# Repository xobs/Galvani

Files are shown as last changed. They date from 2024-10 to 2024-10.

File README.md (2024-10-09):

# Galvani AC LED Controller

A controller for driving pretty lights from AC-driven trains by connecting roller pickups.

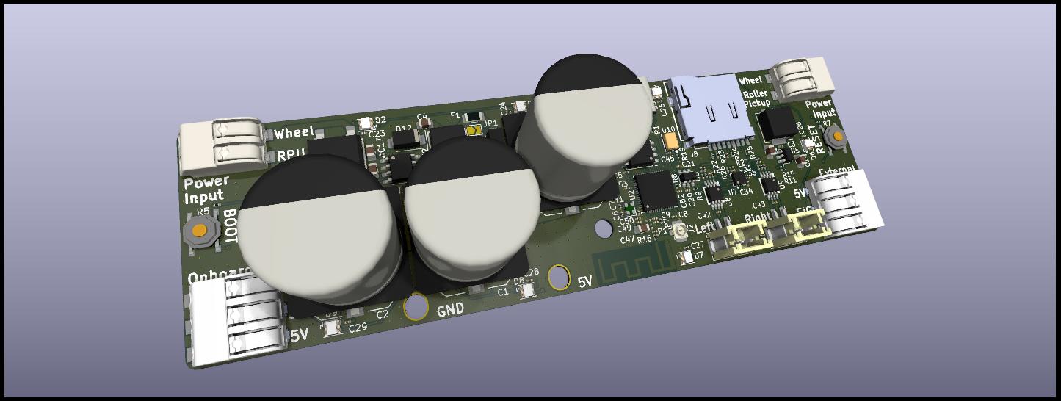
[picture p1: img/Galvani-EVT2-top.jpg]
EVT2 PCB render


Galvani is rated to drive 3 Amps. This is around 40 lights at full bright white, plus the wifi access point. Exceeding this value trips a resettable fuse.

Only run full LEDs when driving from a power supply. When running from USB, only use the onboard LEDs.

## Installation

Install WLED for the ESP32S3. Hold down the "PROG" button as plug in the USB cable. Alternately, hold down "PROG" and press "RESET".

Then, load the firmware using `esptool` or `probe-rs`.

## Testing the LEDs

You should be able to power a short string of LEDs from USB, depending on how much power your USB port can supply.

Use the built-in web interface on WLED. Connect to the access point labelled `WLED-AP`. The password is `wled1234`. Then go to the address `4.3.2.1` in your browser.

You can download an [iOS App](https://apps.apple.com/us/app/wled-native/id6446207239) or [Android App](https://play.google.com/store/apps/details?id=com.pixelheart.wledplus) to control the lights from your phone or tablet.

## Connecting LED Strips

The onboard LEDs are connected to GPIO2. There are 8 onboard LEDs. The end of these LEDs go to the "Onboard" connector, allowing you to add more lights to this string.

There is also an "External" connector. This is connected to GPIO6 and has no onboard LEDs. You can use this connector to avoid having to skip the 8 onboard LEDs when driving a string.

## Connecting to the Roller Pickups

There are two roller pickup connectors. This is designed for setups where there are two pickups to ensure continuity when crossing track connections. You can operate with just one roller pickup, but that may affect the number of lights you can power, and there may be brownouts when crossing segments.

Connect the roller pickup to the connector marked "RPU". If you have two roller pickups, connect each of them to the two connectors.

Next, run a wire from the "EARTH" pin to the wheels. This will provide a return path.

There is no problem connecting both the roller pickups and USB at the same time -- there are a pair of diodes protecting each of the power sources.

**IMPORTANT**: Do not cross-connect RPU and EARTH! That is, do not connect RPU to the roller pickup on one side and RPU to the wheels on the other side! This will create a dead-short.

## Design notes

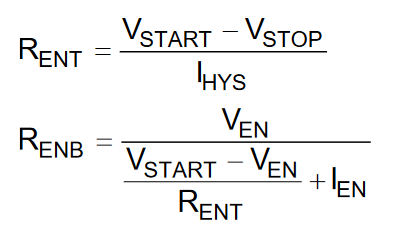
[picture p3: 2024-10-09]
img/12v-uvlo-equation.png

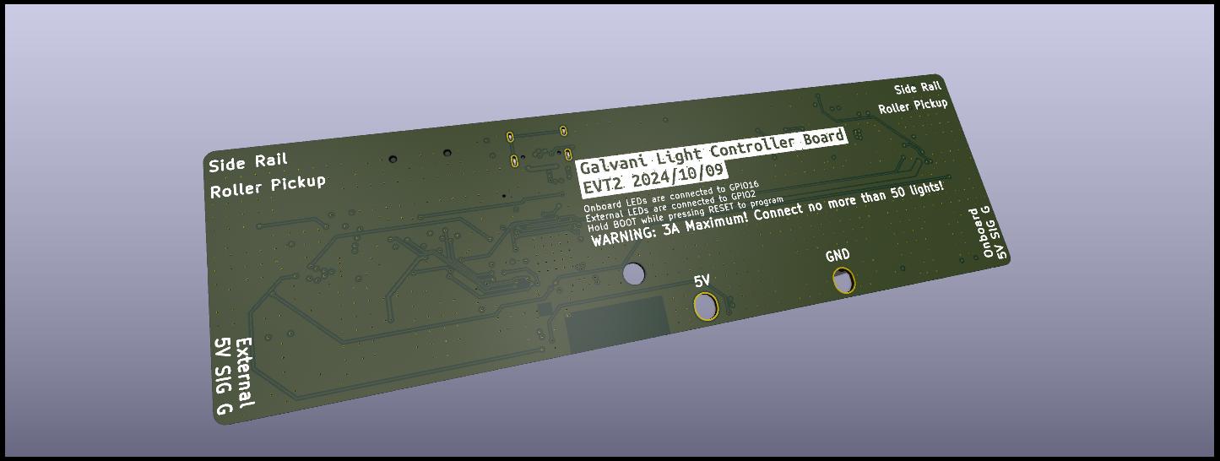
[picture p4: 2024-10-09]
img/Galvani-EVT2-bottom.jpg

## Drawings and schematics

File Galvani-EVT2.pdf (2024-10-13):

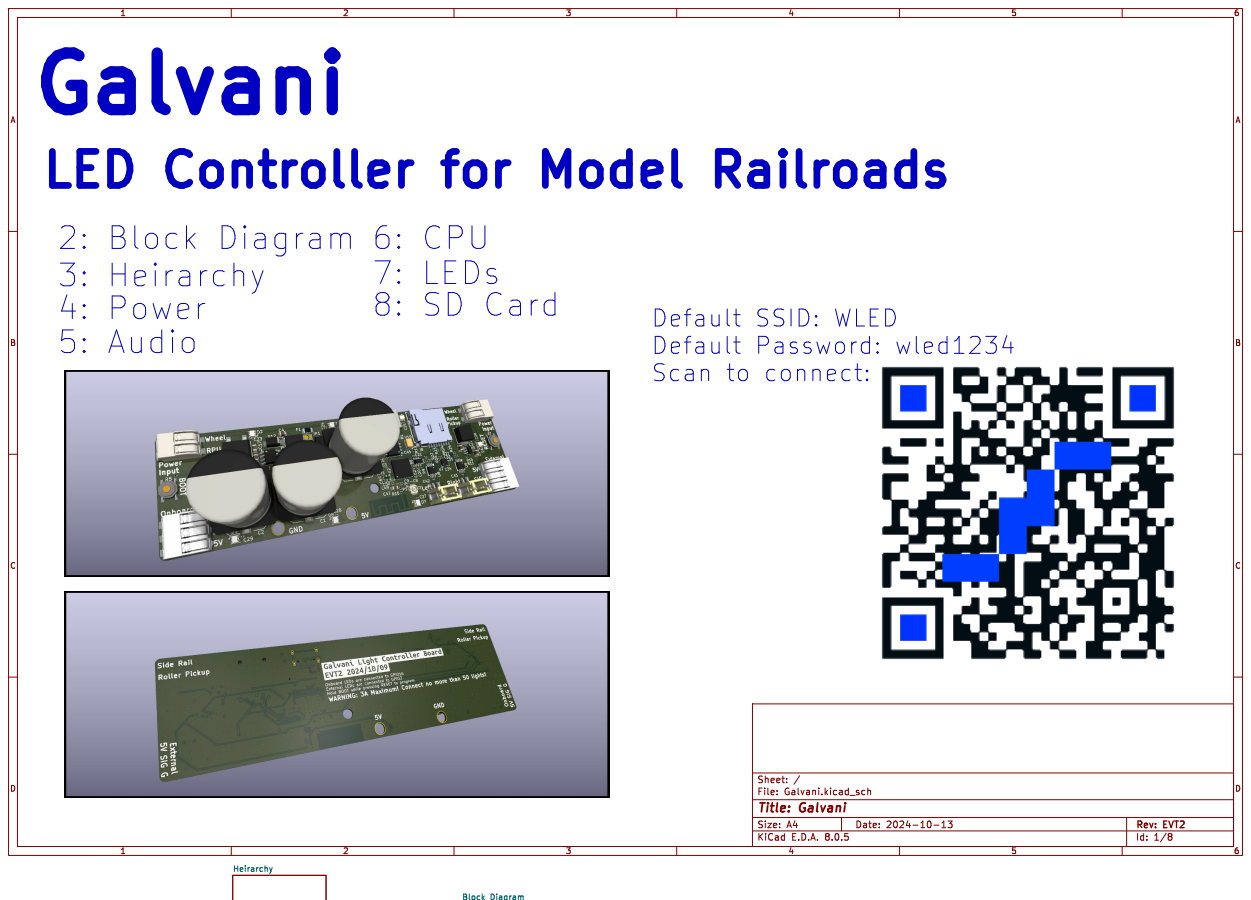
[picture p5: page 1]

Id: 1/8 Title: Galvani File: Galvani.kicad_sch Sheet: / Block Diagram

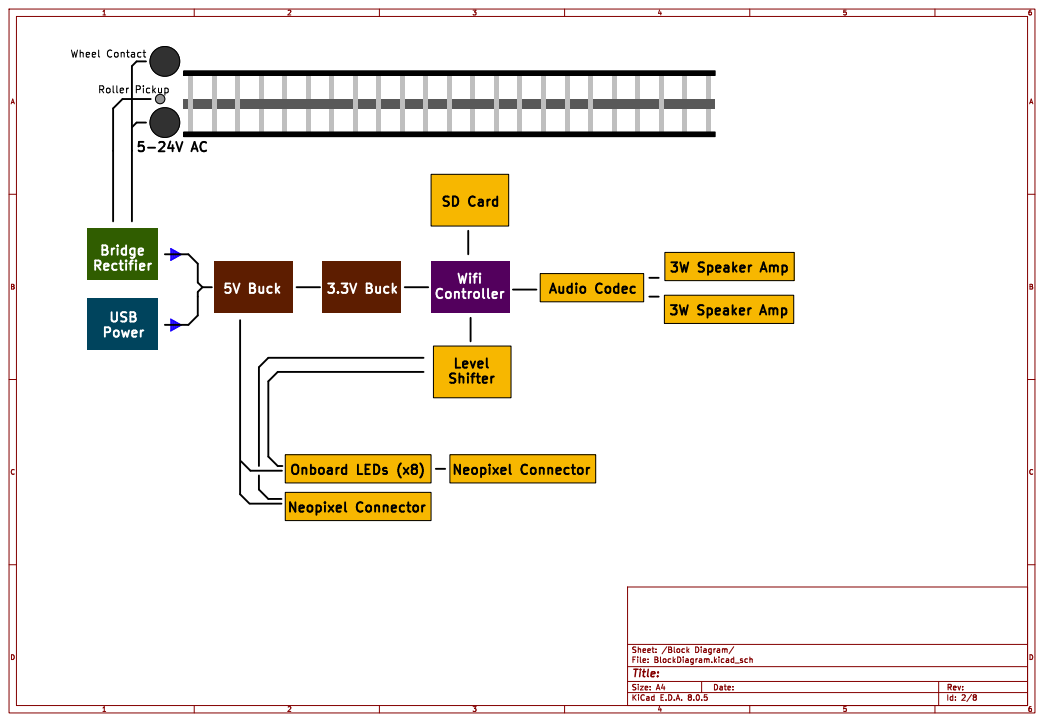
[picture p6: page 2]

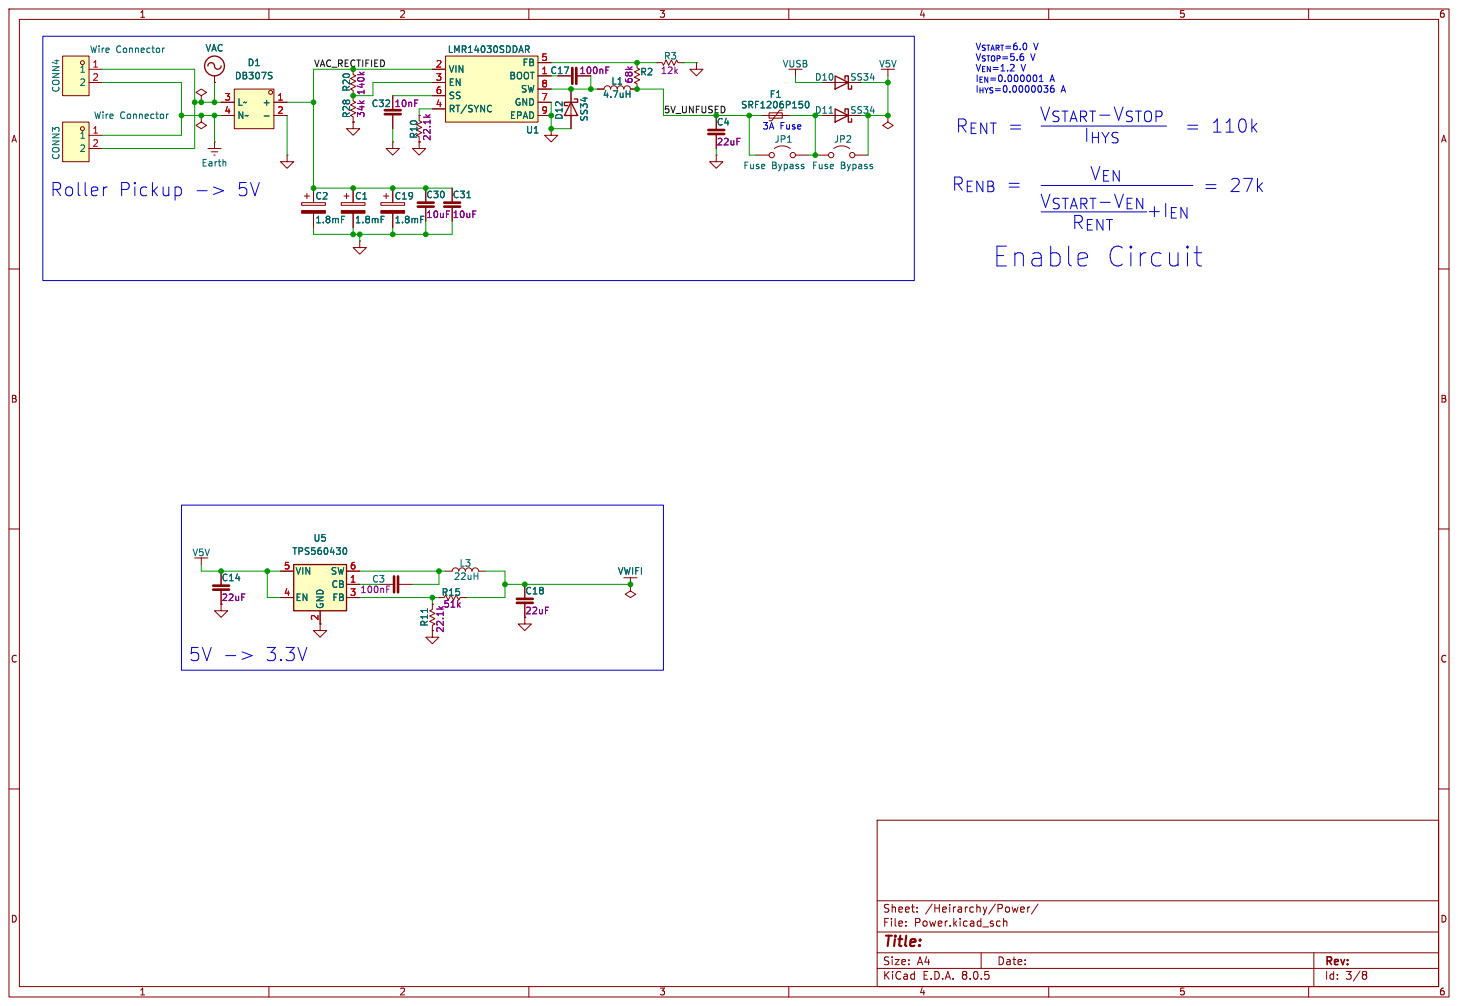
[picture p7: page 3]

VAC_RECTIFIED
Id: 3/8 Title: File: Power.kicad_sch Sheet: /Heirarchy/Power/ R28 34k R20 140k C1

2 FB 3 EN 4 VIN 5 SW 6 U5 V5V TPS560430 C18

2 FB 3 EN 4 VIN 5 SW 6 C18

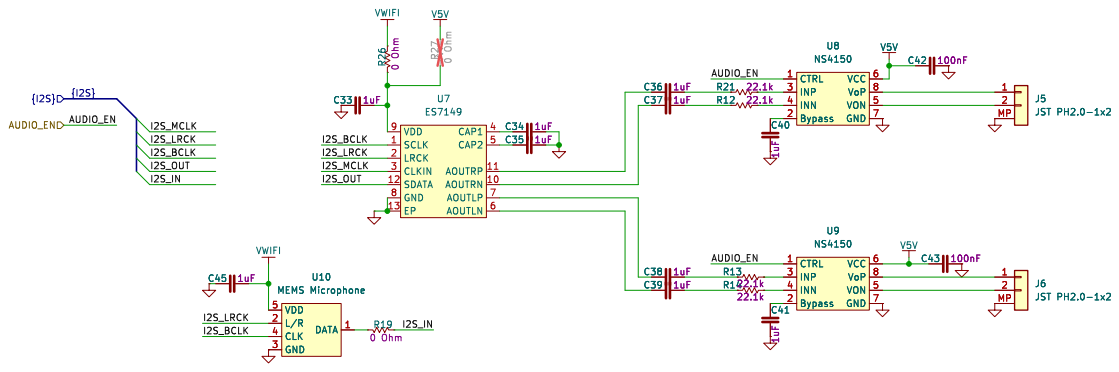
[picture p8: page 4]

AUDIO_EN
Id: 4/8 Title: File: Audio.kicad_sch Sheet: /Heirarchy/Audio/ R13

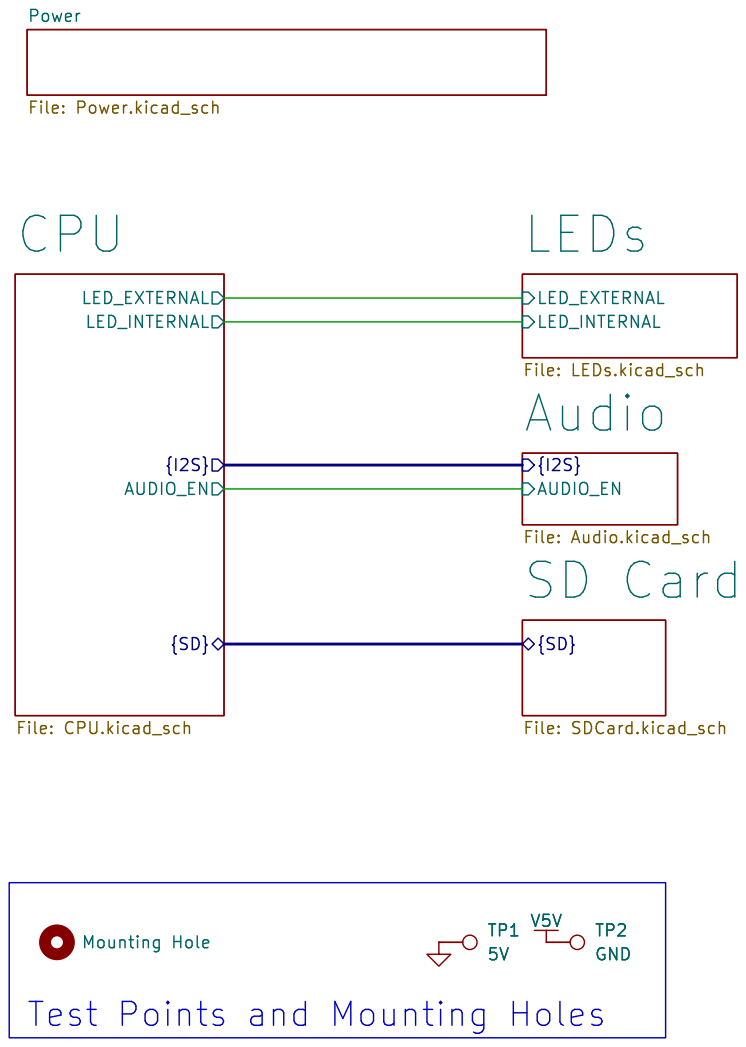
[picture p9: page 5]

File: CPU.kicad_sch Power File: Power.kicad_sch

Id: 5/8 Title: File: Heirarchy.kicad_sch Sheet: /Heirarchy/

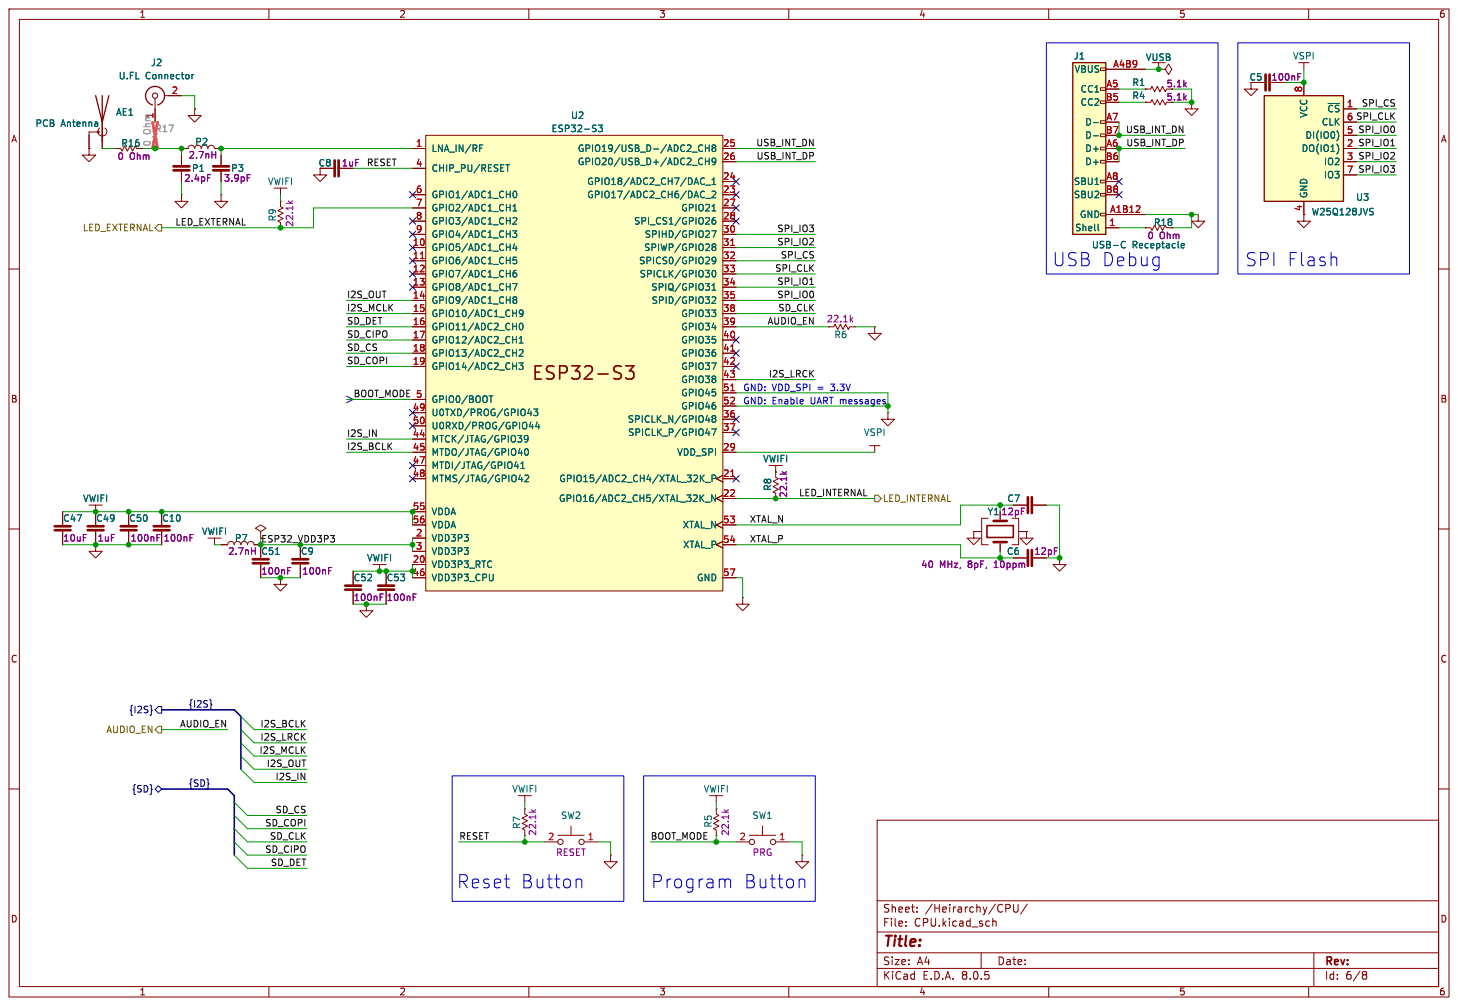
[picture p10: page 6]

Id: 6/8 Title: File: CPU.kicad_sch Sheet: /Heirarchy/CPU/

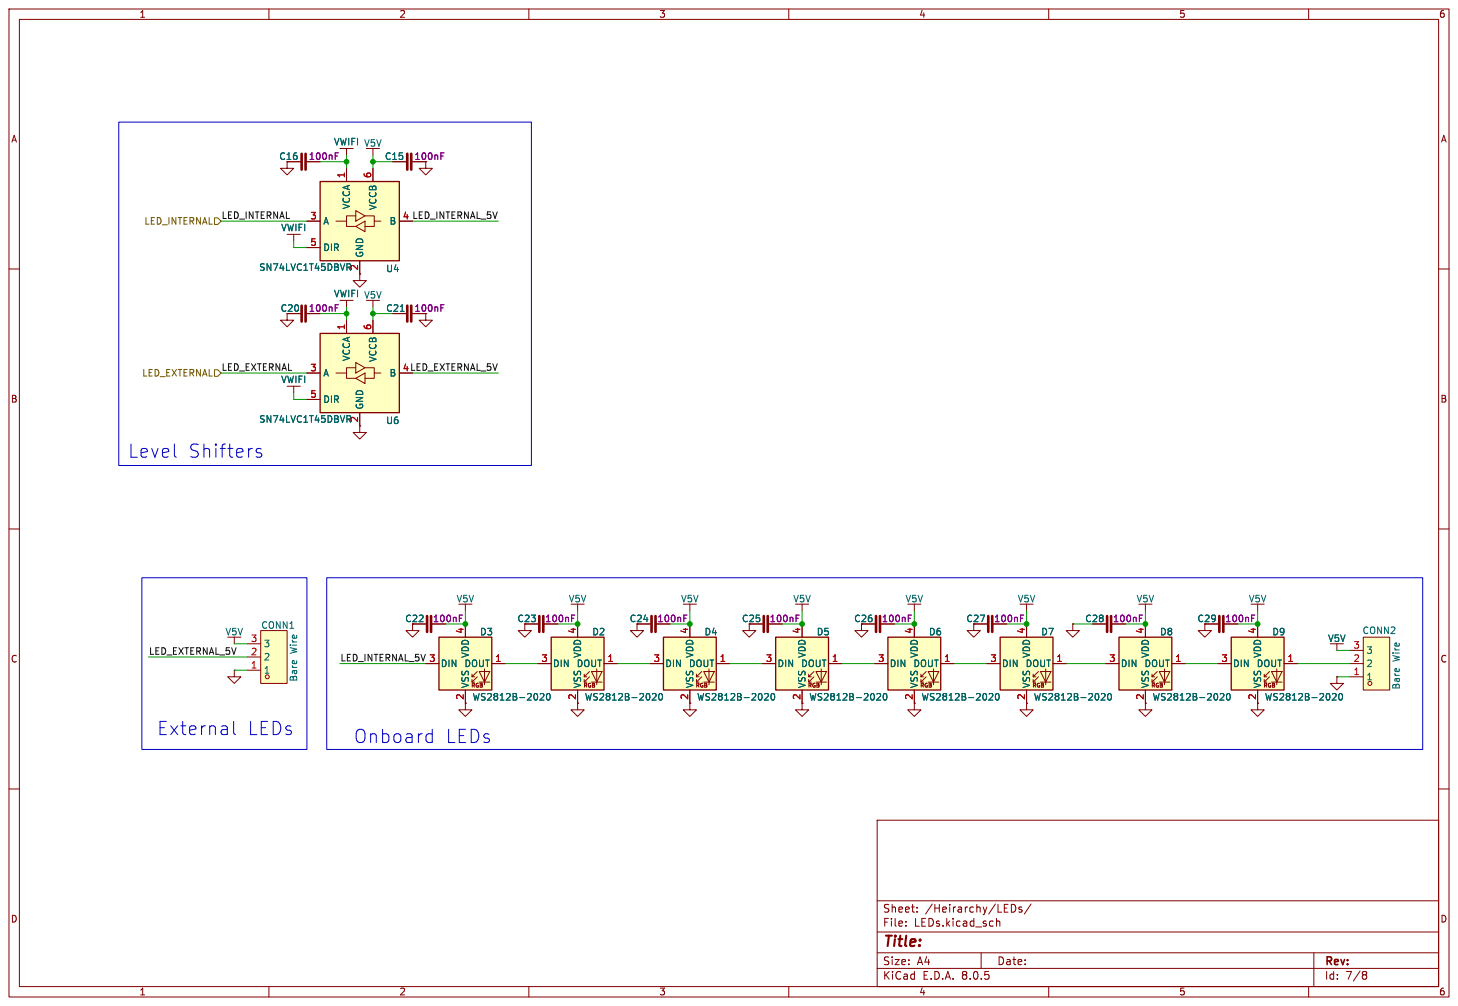
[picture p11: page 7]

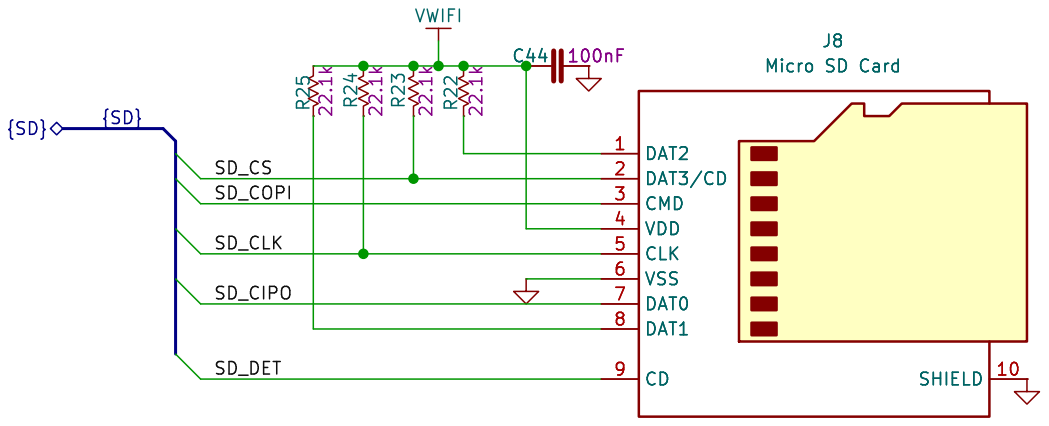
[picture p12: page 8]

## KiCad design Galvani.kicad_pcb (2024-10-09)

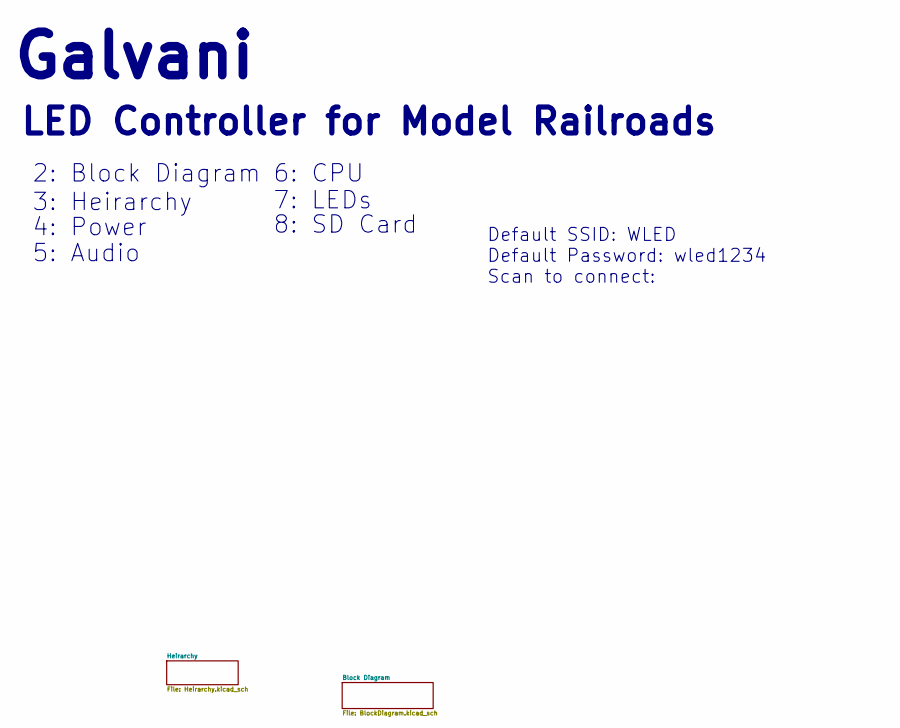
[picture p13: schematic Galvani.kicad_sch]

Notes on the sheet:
5: Audio
Default SSID: WLED Default Password: wled1234 Scan to connect:
LED Controller for Model Railroads
7: LEDs
4: Power
8: SD Card
2: Block Diagram
Galvani
3: Heirarchy
6: CPU

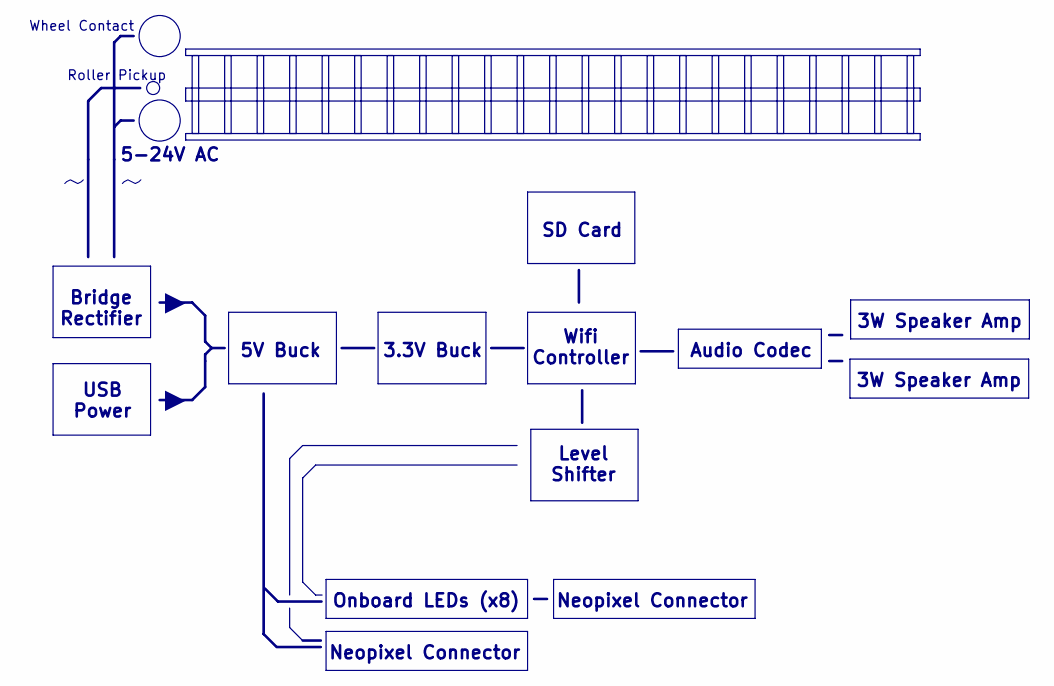
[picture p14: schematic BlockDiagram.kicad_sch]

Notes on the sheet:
Audio Codec
3W Speaker Amp
5V Buck
Onboard LEDs (x8)
Wheel Contact
SD Card
Roller Pickup
Bridge Rectifier
Wifi Controller
5-24V AC
Neopixel Connector
Level Shifter
~ ~
3.3V Buck
USB Power

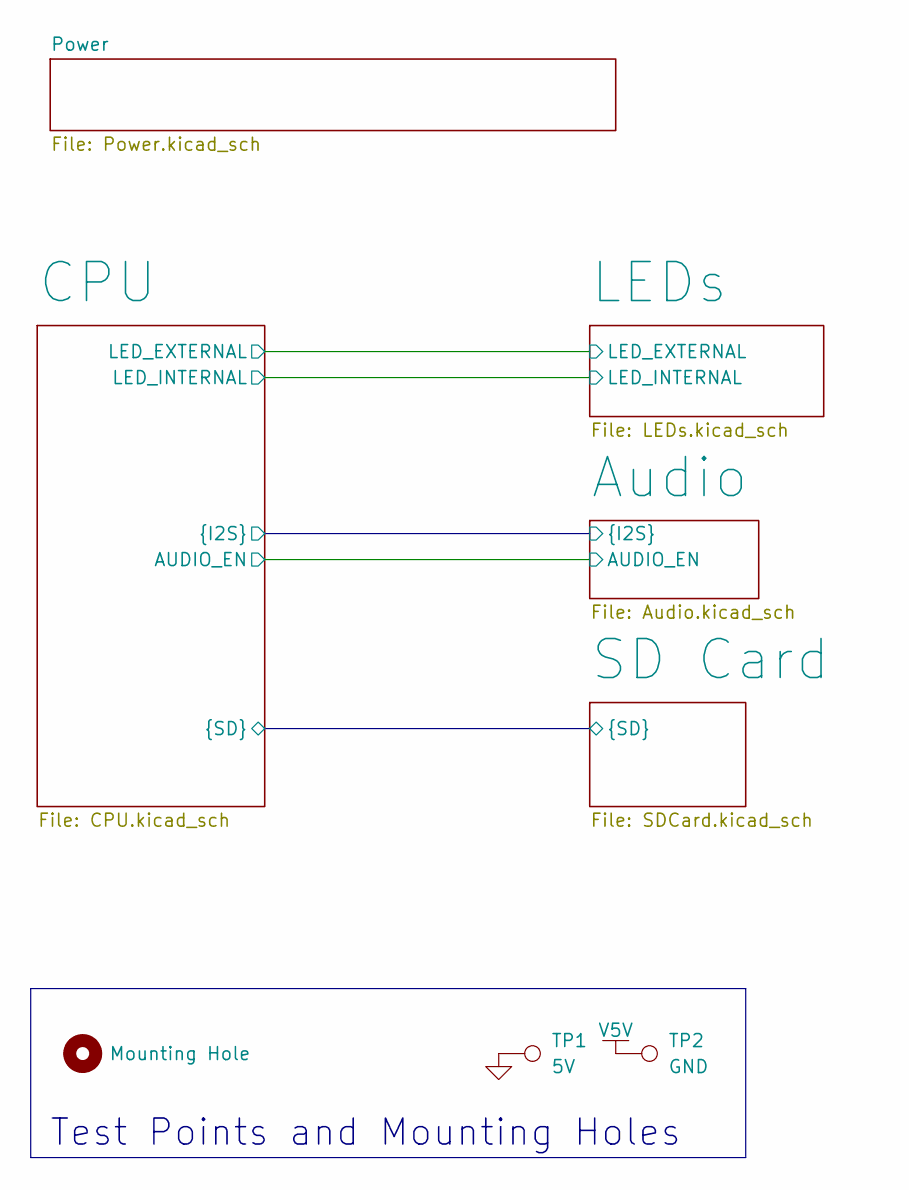
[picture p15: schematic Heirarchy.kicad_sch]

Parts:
H2: Mounting Hole; MountingHole_3.5mm
TP1: 5V; Test Point
TP2: GND; Test Point

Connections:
GND: TP1.1; also elsewhere on the board
V5V: TP2.1; also elsewhere on the board

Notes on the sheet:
Test Points and Mounting Holes

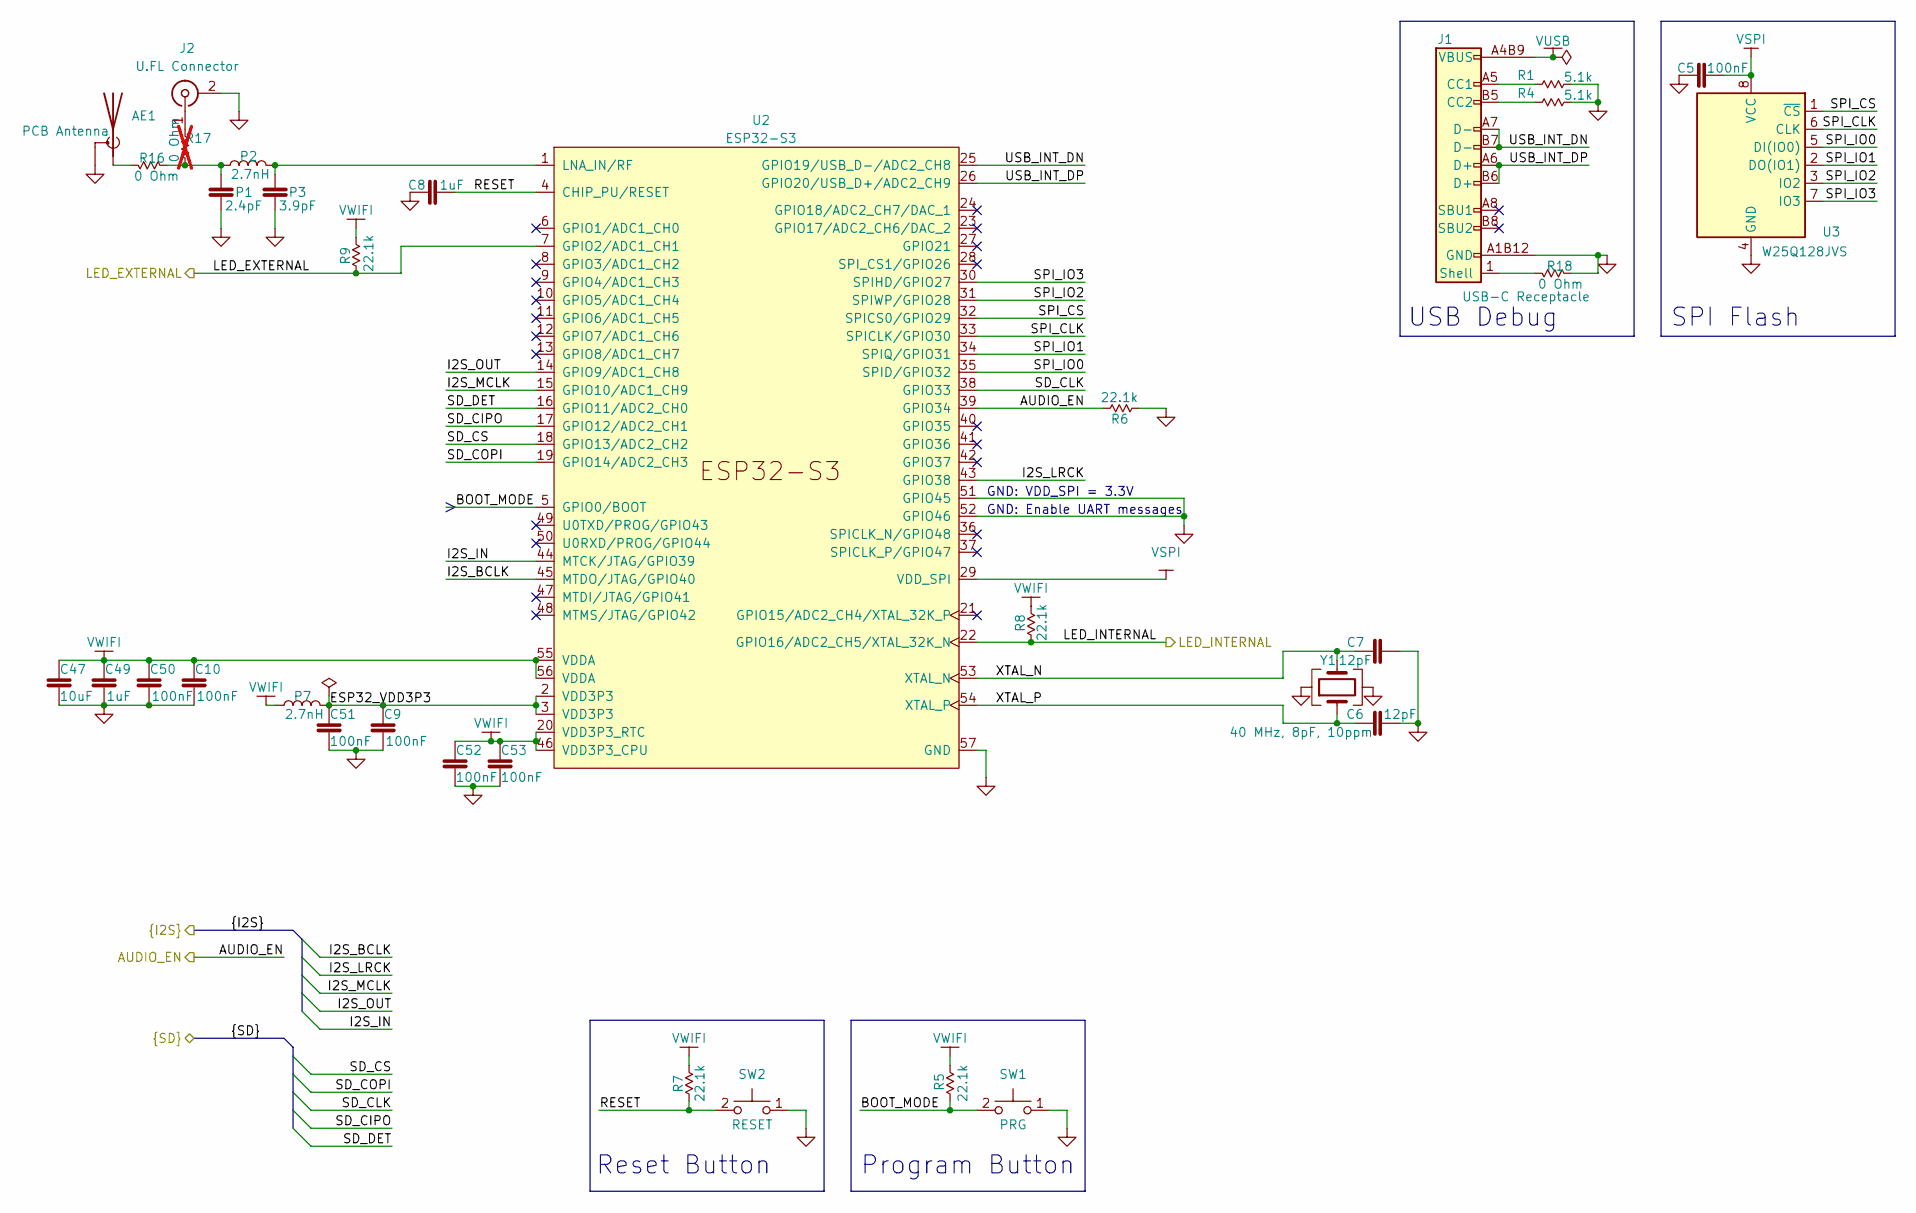
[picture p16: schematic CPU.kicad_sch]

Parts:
AE1: PCB Antenna; Texas_SWRA117D_2.4GHz_Right
C5, C9, C10, C50, C51, C52, C53: Cap 100nF 0201; C_0201_0603Metric
C6, C7: Cap 12pF 0201; C_0201_0603Metric
C8, C49: Cap 1uF 0201; C_0201_0603Metric
C47: Cap 10uF 0805; C_0805_2012Metric; MPN GRM21BR61H106KE43L; LCSC C440198
J1: USB-C Receptacle; USB-C-SMD_TYPE-C16PIN; MPN TYPE-C16PIN; LCSC C393939
J2: U.FL Connector; U.FL_Hirose_U.FL-R-SMT-1_Vertical; MPN BWU.FL-IPEX1; LCSC C5137195
P1: Cap 2.4pF 0201; C_0201_0603Metric; MPN CC0201BRNPO9BN2R4; LCSC C576676
P2, P7: L 2.7nH 0201; L_0201_0603Metric; MPN LQP03PN2N7C02D; LCSC C237548
P3: Cap 3.9pF 0201; C_0201_0603Metric; MPN 0201CG3R9C250NT; LCSC C285100
R1, R4: R 5.1k 0201; R_0201_0603Metric
R5, R6, R7, R8, R9: R 22.1k 0201; R_0201_0603Metric
R16, R18: R 0 ohm 0201; R_0201_0603Metric
R17: R 0 ohm 0201; R_0201_0603Metric; not fitted
SW1, SW2: Pushbutton 4.2x3.2mm 250gf; SW_Push_1P1T_XKB_TS-1187A; MPN TS-1187A-B-A-B; LCSC C318884
U2: ESP32-S3; QFN-56-1EP_7x7mm_P0.4mm_EP5.6x5.6mm_ThermalVias; MPN ESP32-S3
U3: W25Q128JVS; SOIC-8_5.23x5.23mm_P1.27mm; MPN W25Q128JVSIQ; LCSC C97521
Y1: Crystal 40MHz 2016; Crystal_SMD_2016-4Pin_2.0x1.6mm; MPN 7D040000F01; LCSC C648971

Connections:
/Heirarchy/Audio/AUDIO_EN: R6.1, U2.39 (GPIO34); also elsewhere on the board
/Heirarchy/Audio/I2S_BCLK: U2.45 (MTDO/JTAG/GPIO40); also elsewhere on the board
/Heirarchy/Audio/I2S_IN: U2.44 (MTCK/JTAG/GPIO39); also elsewhere on the board
/Heirarchy/Audio/I2S_LRCK: U2.43 (GPIO38); also elsewhere on the board
/Heirarchy/Audio/I2S_MCLK: U2.15 (GPIO10/ADC1_CH9); also elsewhere on the board
/Heirarchy/Audio/I2S_OUT: U2.14 (GPIO9/ADC1_CH8); also elsewhere on the board
/Heirarchy/CPU/BOOT_MODE: R5.2, SW1.2, U2.5 (GPIO0/BOOT)
/Heirarchy/CPU/ESP32_VDD3P3: C9.1, C51.1, P7.2, U2.2 (VDD3P3), U2.3 (VDD3P3)
/Heirarchy/CPU/LED_EXTERNAL: R9.2, U2.7 (GPIO2/ADC1_CH1); also elsewhere on the board
/Heirarchy/CPU/LED_INTERNAL: R8.2, U2.22 (GPIO16/ADC2_CH5/XTAL_32K_N); also elsewhere on the board
/Heirarchy/CPU/RESET: C8.1, R7.2, SW2.2, U2.4 (CHIP_PU/RESET)
/Heirarchy/CPU/SD_CIPO: U2.17 (GPIO12/ADC2_CH1); also elsewhere on the board
/Heirarchy/CPU/SD_CLK: U2.38 (GPIO33); also elsewhere on the board
/Heirarchy/CPU/SD_COPI: U2.19 (GPIO14/ADC2_CH3); also elsewhere on the board
/Heirarchy/CPU/SD_CS: U2.18 (GPIO13/ADC2_CH2); also elsewhere on the board
/Heirarchy/CPU/SD_DET: U2.16 (GPIO11/ADC2_CH0); also elsewhere on the board
/Heirarchy/CPU/SPI_CLK: U2.33 (SPICLK/GPIO30), U3.6 (CLK)
/Heirarchy/CPU/SPI_CS: U2.32 (SPICS0/GPIO29), U3.1 (~CS)
/Heirarchy/CPU/SPI_IO0: U2.35 (SPID/GPIO32), U3.5 (DI(IO0))
/Heirarchy/CPU/SPI_IO1: U2.34 (SPIQ/GPIO31), U3.2 (DO(IO1))
/Heirarchy/CPU/SPI_IO2: U2.31 (SPIWP/GPIO28), U3.3 (IO2)
/Heirarchy/CPU/SPI_IO3: U2.30 (SPIHD/GPIO27), U3.7 (IO3)
/Heirarchy/CPU/USB_INT_DN: J1.A7 (D-), J1.B7 (D-), U2.25 (GPIO19/USB_D-/ADC2_CH8)
/Heirarchy/CPU/USB_INT_DP: J1.A6 (D+), J1.B6 (D+), U2.26 (GPIO20/USB_D+/ADC2_CH9)
/Heirarchy/CPU/XTAL_N: C7.2, U2.53 (XTAL_N), Y1.3
/Heirarchy/CPU/XTAL_P: C6.1, U2.54 (XTAL_P), Y1.1
GND: AE1.2 (Shield), C5.2, C6.2, C7.1, C8.2, C9.2, C10.2, C47.2, C49.2, C50.2, C51.2, C52.2, C53.2, J1.A1B12 (GND), J1.B1A12 (GND), J2.2 (Ext), P1.1, P3.1, R1.2, R4.2, R6.2, R18.1, SW1.1, SW2.1, U2.51 (GPIO45), U2.52 (GPIO46), U2.57 (GND), U3.4 (GND), Y1.2, Y1.4; also elsewhere on the board
unnamed: AE1.1 (A), R16.2
unnamed: J1.A5 (CC1), R1.1
unnamed: J1.B5 (CC2), R4.1
unnamed: J1.1 (Shell), J1.2 (Shell), J1.3 (Shell), J1.4 (Shell), R18.2
unnamed: J2.1 (In), R17.1
unnamed: P1.2, P2.1, R16.1, R17.2
unnamed: P2.2, P3.2, U2.1 (LNA_IN/RF)
VSPI: C5.1, U2.29 (VDD_SPI), U3.8 (VCC)
VUSB: J1.A4B9 (VBUS), J1.B4A9 (VBUS); also elsewhere on the board
VWIFI: C10.1, C47.1, C49.1, C50.1, C52.1, C53.1, P7.1, R5.1, R7.1, R8.1, R9.1, U2.20 (VDD3P3_RTC), U2.46 (VDD3P3_CPU), U2.55 (VDDA), U2.56 (VDDA); also elsewhere on the board

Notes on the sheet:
SPI Flash
Program Button
Reset Button
GND: Enable UART messages
GND: VDD_SPI = 3.3V
USB Debug

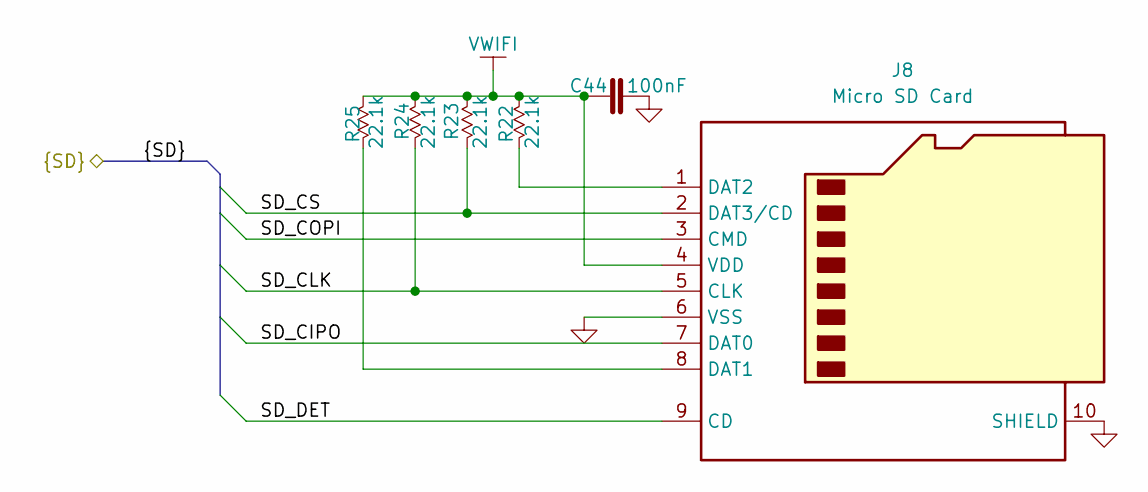
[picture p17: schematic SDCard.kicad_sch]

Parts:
C44: Cap 100nF 0201; C_0201_0603Metric
J8: Micro SD Card; TF-SMD_TF-PUSH; MPN TF PUSH; LCSC C393941
R22, R23, R24, R25: R 22.1k 0201; R_0201_0603Metric

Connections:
/Heirarchy/CPU/SD_CIPO: J8.7 (DAT0); also elsewhere on the board
/Heirarchy/CPU/SD_CLK: J8.5 (CLK), R24.2; also elsewhere on the board
/Heirarchy/CPU/SD_COPI: J8.3 (CMD); also elsewhere on the board
/Heirarchy/CPU/SD_CS: J8.2 (DAT3/CD), R23.2; also elsewhere on the board
/Heirarchy/CPU/SD_DET: J8.9 (CD); also elsewhere on the board
GND: C44.1, J8.6 (VSS), J8.10 (SHIELD), J8.11 (SHIELD), J8.12 (SHIELD), J8.13 (SHIELD); also elsewhere on the board
unnamed: J8.8 (DAT1), R25.2
unnamed: J8.1 (DAT2), R22.2
VWIFI: C44.2, J8.4 (VDD), R22.1, R23.1, R24.1, R25.1; also elsewhere on the board

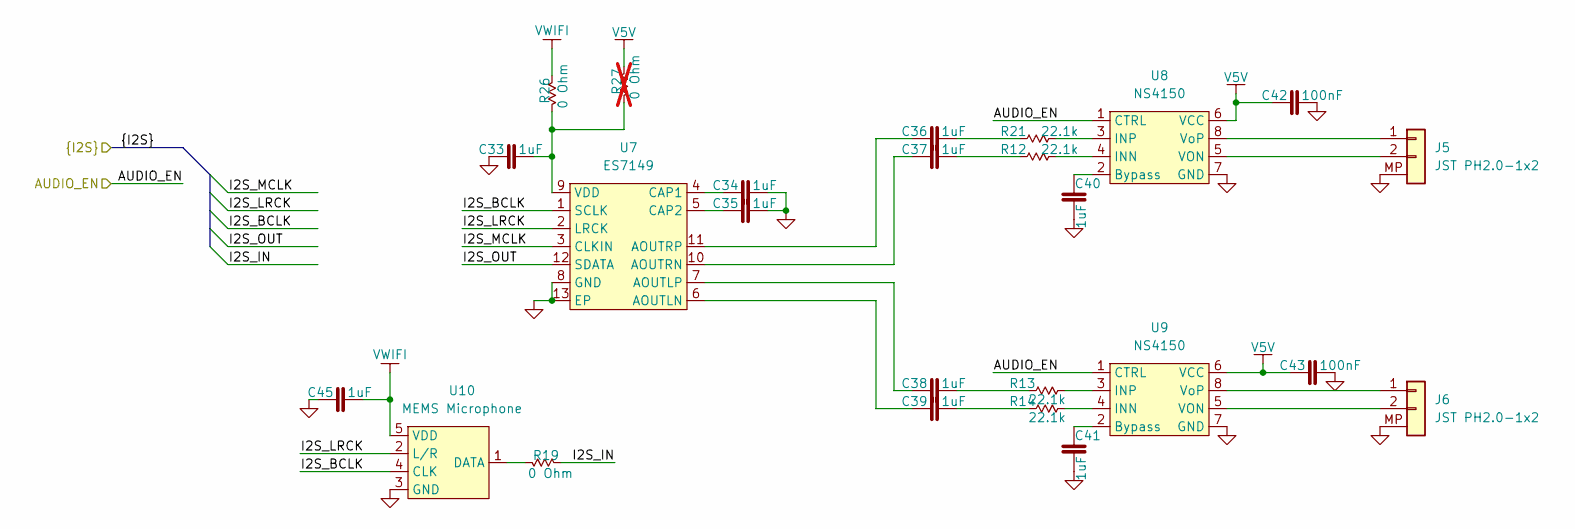
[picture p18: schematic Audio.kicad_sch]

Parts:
C33, C34, C35, C36, C37, C38, C39, C40, C41, C45: Cap 1uF 0201; C_0201_0603Metric
C42, C43: Cap 100nF 0201; C_0201_0603Metric
J5, J6: JST PH2.0-1x2; JST_PH_B2B-PH-SM4-TB_1x02-1MP_P2.00mm_Vertical; MPN B2B-PH-SM4-TB(LF)(SN); LCSC C160352
R12, R13, R14, R21: R 22.1k 0201; R_0201_0603Metric
R19, R26: R 0 ohm 0201; R_0201_0603Metric
R27: R 0 ohm 0201; R_0201_0603Metric; not fitted
U7: ES7149; QFN-12_L2.5-W2.5-P0.50-BL-EP; Manufacturer Part ES7149; LCSC C365753
U8, U9: NS4150; MSOP-8_L3.0-W3.0-P0.65-LS5.0-BL; Manufacturer Part NS4150B; LCSC C189961
U10: MEMS Microphone; RHLGA-5L_L3.5-W2.7-P0.82-MP23ABS1TR; Manufacturer Part SD18OB371-041; LCSC C3040249

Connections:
/Heirarchy/Audio/AUDIO_EN: U8.1 (CTRL), U9.1 (CTRL); also elsewhere on the board
/Heirarchy/Audio/I2S_BCLK: U7.1 (SCLK), U10.4 (CLK); also elsewhere on the board
/Heirarchy/Audio/I2S_IN: R19.1; also elsewhere on the board
/Heirarchy/Audio/I2S_LRCK: U7.2 (LRCK), U10.2 (L/R); also elsewhere on the board
/Heirarchy/Audio/I2S_MCLK: U7.3 (CLKIN); also elsewhere on the board
/Heirarchy/Audio/I2S_OUT: U7.12 (SDATA); also elsewhere on the board
GND: C33.1, C34.2, C35.2, C40.2, C41.2, C42.2, C43.2, C45.1, J5.MP, J6.MP, U7.8 (GND), U7.13 (EP), U8.7 (GND), U9.7 (GND), U10.3 (GND); also elsewhere on the board
unnamed: C36.2, R21.1
unnamed: C37.2, R12.1
unnamed: C38.2, R13.1
unnamed: C39.2, R14.1
unnamed: J5.1, U8.8 (VoP)
unnamed: J5.2, U8.5 (VON)
unnamed: J6.1, U9.8 (VoP)
unnamed: J6.2, U9.5 (VON)
unnamed: C39.1, U7.6 (AOUTLN)
unnamed: C38.1, U7.7 (AOUTLP)
unnamed: C37.1, U7.10 (AOUTRN)
unnamed: C36.1, U7.11 (AOUTRP)
unnamed: C34.1, U7.4 (CAP1)
unnamed: C35.1, U7.5 (CAP2)
unnamed: C33.2, R26.2, R27.2, U7.9 (VDD)
unnamed: C40.1, U8.2 (Bypass)
unnamed: R12.2, U8.4 (INN)
unnamed: R21.2, U8.3 (INP)
unnamed: C41.1, U9.2 (Bypass)
unnamed: R14.2, U9.4 (INN)
unnamed: R13.2, U9.3 (INP)
unnamed: R19.2, U10.1 (DATA)
V5V: C42.1, C43.1, R27.1, U8.6 (VCC), U9.6 (VCC); also elsewhere on the board
VWIFI: C45.2, R26.1, U10.5 (VDD); also elsewhere on the board

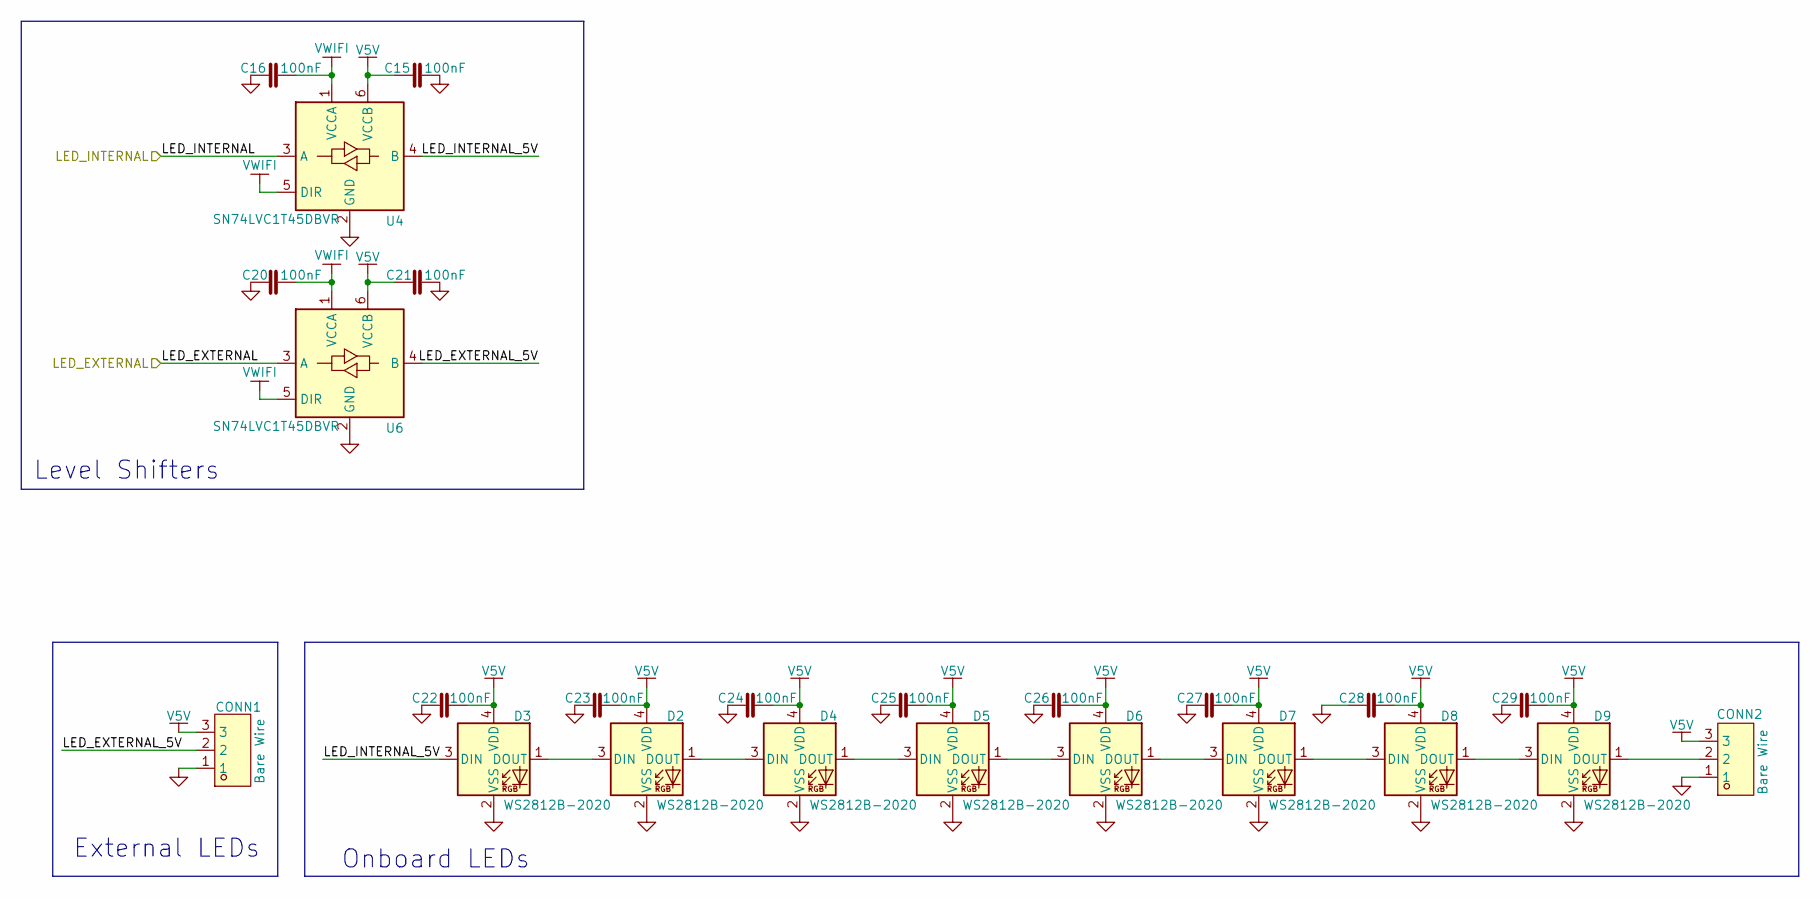
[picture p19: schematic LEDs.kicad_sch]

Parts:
C15, C16, C20, C21, C22, C23, C24, C25, C26, C27, C28, C29: Cap 100nF 0201; C_0201_0603Metric
CONN1, CONN2: Bare Wire; CONN-SMD_2060-453; MPN 2060-453/998-404; LCSC C2765056
D2, D3, D4, D5, D6, D7, D8, D9: WS2812B-2020; LED_WS2812B-2020_PLCC4_2.0x2.0mm; MPN WS2812C-2020-V1; LCSC C965555
U4, U6: SN74LVC1T45DBVR; SOT-23-6; MPN SN74LVC1T45DBVR; LCSC C7843

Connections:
/Heirarchy/CPU/LED_EXTERNAL: U6.3 (A); also elsewhere on the board
/Heirarchy/CPU/LED_INTERNAL: U4.3 (A); also elsewhere on the board
/Heirarchy/LEDs/LED_EXTERNAL_5V: CONN1.2, U6.4 (B)
/Heirarchy/LEDs/LED_INTERNAL_5V: D3.3 (DIN), U4.4 (B)
GND: C15.2, C16.1, C20.1, C21.2, C22.2, C23.2, C24.2, C25.2, C26.2, C27.2, C28.2, C29.2, CONN1.1, CONN2.1, D2.2 (VSS), D3.2 (VSS), D4.2 (VSS), D5.2 (VSS), D6.2 (VSS), D7.2 (VSS), D8.2 (VSS), D9.2 (VSS), U4.2 (GND), U6.2 (GND); also elsewhere on the board
unnamed: D2.3 (DIN), D3.1 (DOUT)
unnamed: D2.1 (DOUT), D4.3 (DIN)
unnamed: D4.1 (DOUT), D5.3 (DIN)
unnamed: D5.1 (DOUT), D6.3 (DIN)
unnamed: D6.1 (DOUT), D7.3 (DIN)
unnamed: D7.1 (DOUT), D8.3 (DIN)
unnamed: D8.1 (DOUT), D9.3 (DIN)
unnamed: CONN2.2, D9.1 (DOUT)
V5V: C15.1, C21.1, C22.1, C23.1, C24.1, C25.1, C26.1, C27.1, C28.1, C29.1, CONN1.3, CONN2.3, D2.4 (VDD), D3.4 (VDD), D4.4 (VDD), D5.4 (VDD), D6.4 (VDD), D7.4 (VDD), D8.4 (VDD), D9.4 (VDD), U4.6 (VCCB), U6.6 (VCCB); also elsewhere on the board
VWIFI: C16.2, C20.2, U4.1 (VCCA), U4.5 (DIR), U6.1 (VCCA), U6.5 (DIR); also elsewhere on the board

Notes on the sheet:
Level Shifters
Onboard LEDs
External LEDs

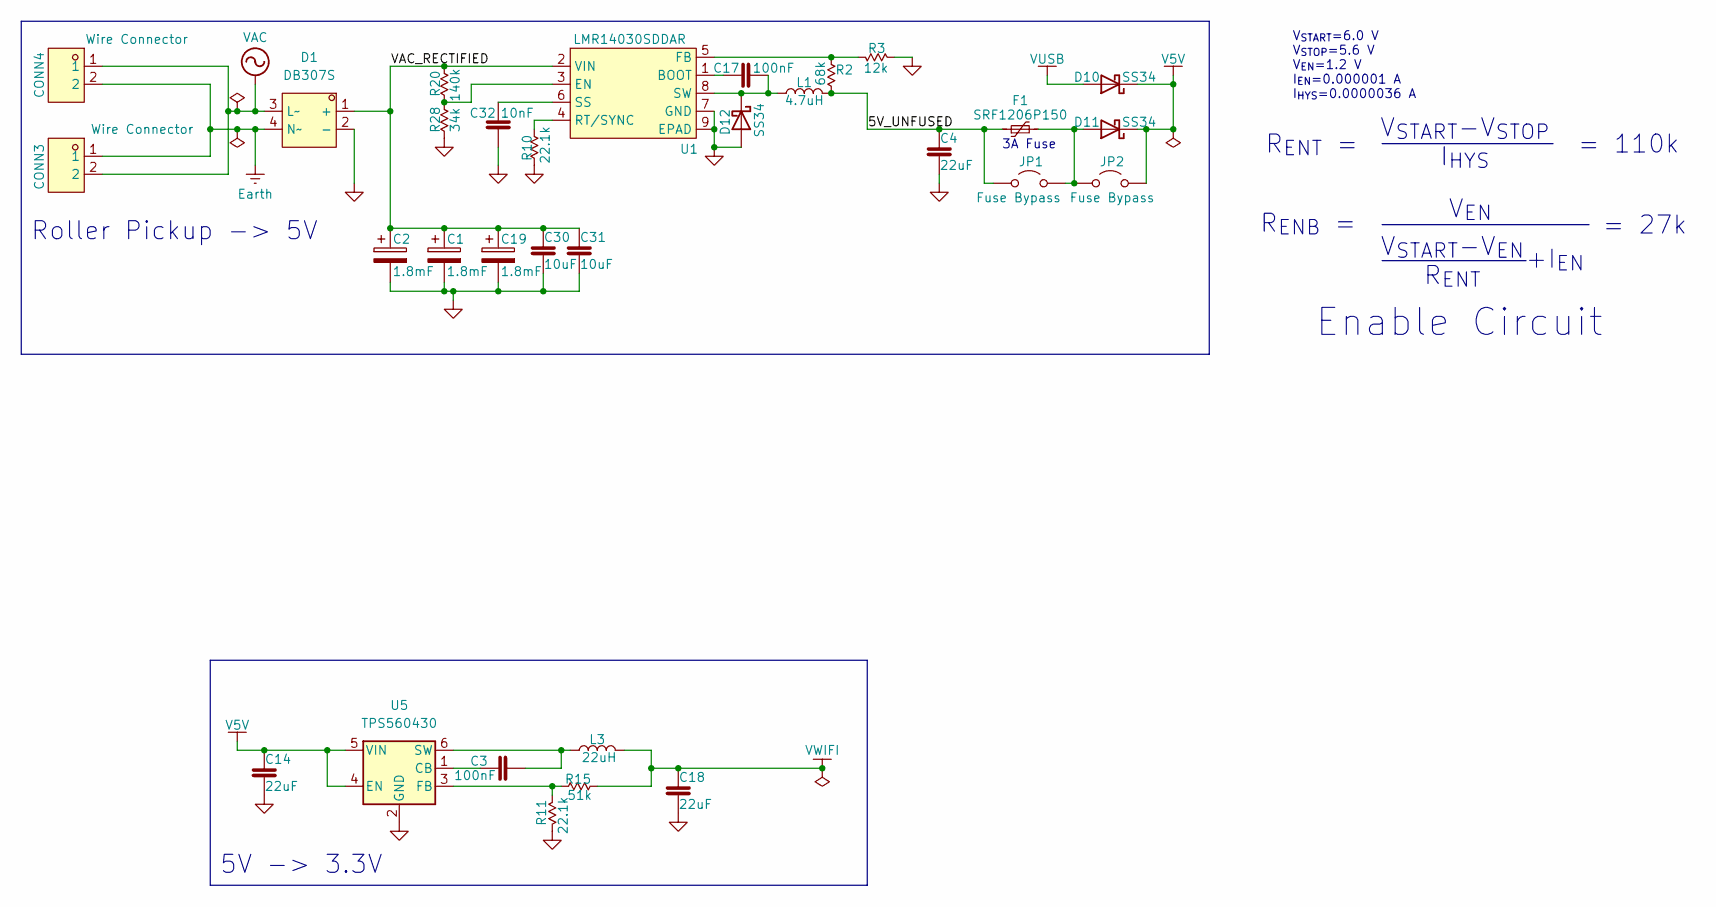
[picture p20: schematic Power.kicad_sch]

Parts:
C1, C2, C19: 1.8mF; CAP-SMD_BD18.0-L21.5-W21.5; MPN VUX182M1VTR-1821; LCSC C3029717
C3, C17: Cap 100nF 0201; C_0201_0603Metric
C4, C14, C18: Cap 22uF 0805; C_0805_2012Metric; MPN CL21A226MAQNNNE; LCSC C45783
C30, C31: Cap 10uF 0805; C_0805_2012Metric; MPN GRM21BR61H106KE43L; LCSC C440198
C32: Cap 10nF 0201; C_0201_0603Metric
CONN3, CONN4: Wire Connector; CONN-SMD_2060-452; MPN 2060-452/998-404; LCSC C2765055
D1: DB307S; DB-S_L8.3-W6.4-P5.10-LS9.9-TL; MPN DB307S; LCSC C3011148
D10, D11, D12: SS34; D_SMA; MPN SS34; LCSC C8678
F1: SRF1206P150; Fuse_1206_3216Metric; MPN SRF1206P150; LCSC C2838983
JP1, JP2: Fuse Bypass; SolderJumper-2_P1.3mm_Open_TrianglePad1.0x1.5mm
L1: 4.7uH; IND-SMD_L7.2-W6.6_GPSR07X0; MPN CYA0630-4.7UH; LCSC C5189748
L3: 22uH; IND-SMD_L7.1-W6.6; MPN YSPI0630A-220M; LCSC C497873
R2: R 68k 0201; R_0201_0603Metric
R3: R 12k 0201; R_0201_0603Metric
R10, R11: R 22.1k 0201; R_0201_0603Metric
R15: R 51k 0201; R_0201_0603Metric
R20: R 140k 0201; R_0201_0603Metric
R28: R 34k 0201; R_0201_0603Metric
U1: LMR14030SDDAR; SOIC-8-1EP_3.9x4.9mm_P1.27mm_EP2.41x3.3mm_ThermalVias; MPN LMR14030SDDAR; LCSC C182078
U5: TPS560430; SOT-23-6; MPN TPS560430XDBVR; LCSC C524782

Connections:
/Heirarchy/Power/5V_UNFUSED: C4.1, F1.1, JP1.1 (A), L1.2, R2.2
/Heirarchy/Power/VAC_RECTIFIED: C1.1, C2.1, C19.1, C30.1, C31.1, D1.1 (+), R20.1, U1.2 (VIN)
Earth: CONN3.1, CONN4.2, D1.4 (N~)
GND: C1.2, C2.2, C4.2, C14.2, C18.2, C19.2, C30.2, C31.2, C32.1, D1.2 (-), D12.2 (A), R3.2, R10.1, R11.2, R28.2, U1.7 (GND), U1.9 (EPAD), U5.2 (GND); also elsewhere on the board
unnamed: D11.2 (A), F1.2, JP1.2 (B), JP2.1 (A)
unnamed: C17.1, D12.1 (K), L1.1, U1.8 (SW)
unnamed: C17.2, U1.1 (BOOT)
unnamed: R20.2, R28.1, U1.3 (EN)
unnamed: R2.1, R3.1, U1.5 (FB)
unnamed: R10.2, U1.4 (RT/SYNC)
unnamed: C32.2, U1.6 (SS)
unnamed: C3.2, U5.1 (CB)
unnamed: R11.1, R15.1, U5.3 (FB)
unnamed: C3.1, L3.1, U5.6 (SW)
V5V: C14.1, D10.1 (K), D11.1 (K), JP2.2 (B), U5.4 (EN), U5.5 (VIN); also elsewhere on the board
VAC: CONN3.2, CONN4.1, D1.3 (L~)
VUSB: D10.2 (A); also elsewhere on the board
VWIFI: C18.1, L3.2, R15.2; also elsewhere on the board

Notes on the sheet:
R_{ENB} =
V_{EN}
= 110k
5V -> 3.3V
Roller Pickup -> 5V
V_{START}-V_{EN} R_{ENT}
R_{ENT} =
V_{START}-V_{STOP} I_{HYS}
Enable Circuit
V_{START}=6.0 V V_{STOP}=5.6 V V_{EN}=1.2 V I_{EN}=0.000001 A I_{HYS}=0.0000036 A
= 27k
3A Fuse
+I_{EN}

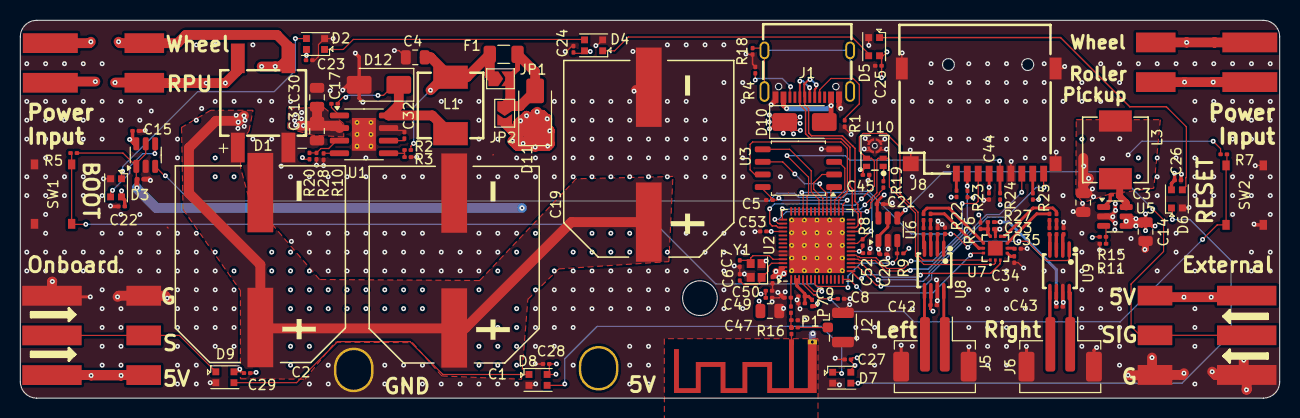
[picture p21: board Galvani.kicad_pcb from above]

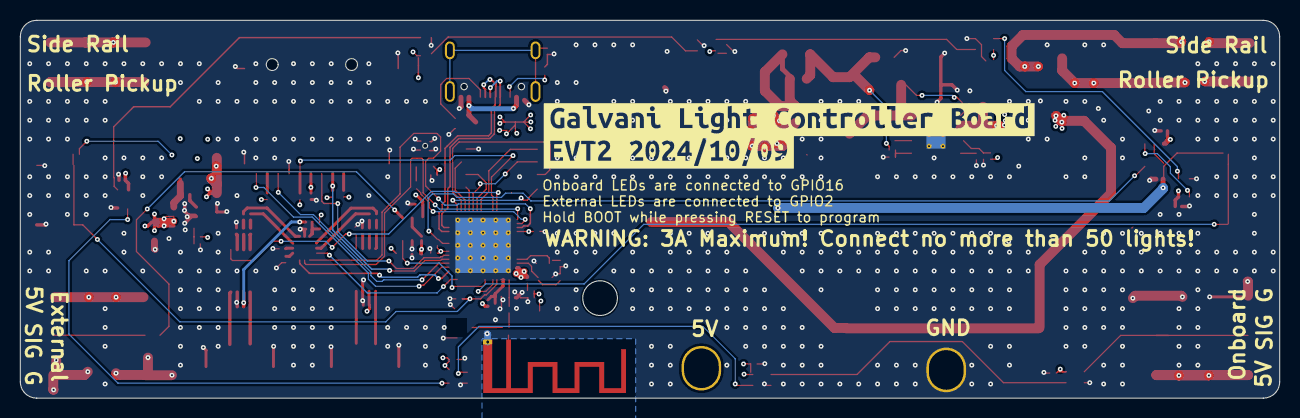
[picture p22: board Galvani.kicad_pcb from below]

Board: 4 copper layers, 127.0 x 38.1 mm, 125 parts (2 on the bottom side), 86 nets.

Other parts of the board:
kibuzzard-66F0D9A1: G***; kibuzzard-66F0D9A1
kibuzzard-67065BC0: G***; kibuzzard-67065BC0

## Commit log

2024-09-22 initial commit: schematic done
    [Galvani.kicad_pcb, Galvani.kicad_sch]
2024-09-22 layout complete
    [Galvani.kicad_pcb, Galvani.kicad_sch]
2024-09-23 evt1: initial release
    [Galvani.kicad_pcb, Galvani.kicad_sch]
2024-09-23 pdf: add schematic pdf file
2024-10-08 evt2: finish pcb
    [Audio.kicad_sch, BlockDiagram.kicad_sch, CPU.kicad_sch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]
2024-10-09 release evt2
    [Audio.kicad_sch, CPU.kicad_sch, Galvani.kicad_pcb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]
2024-10-13 change schematic version to EVT2
    [Galvani.kicad_sch]
